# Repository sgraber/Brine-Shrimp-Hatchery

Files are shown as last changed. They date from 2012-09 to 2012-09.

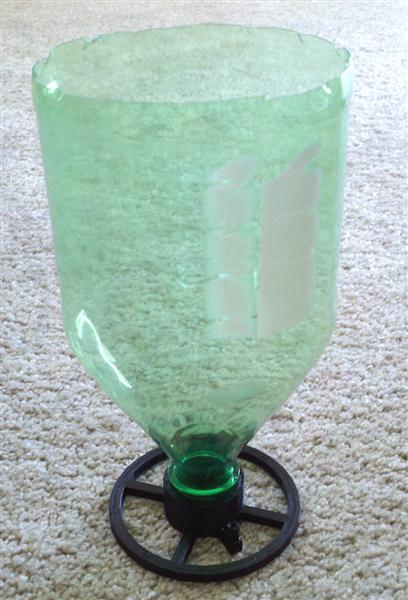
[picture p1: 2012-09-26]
hatchery-assembled.jpg

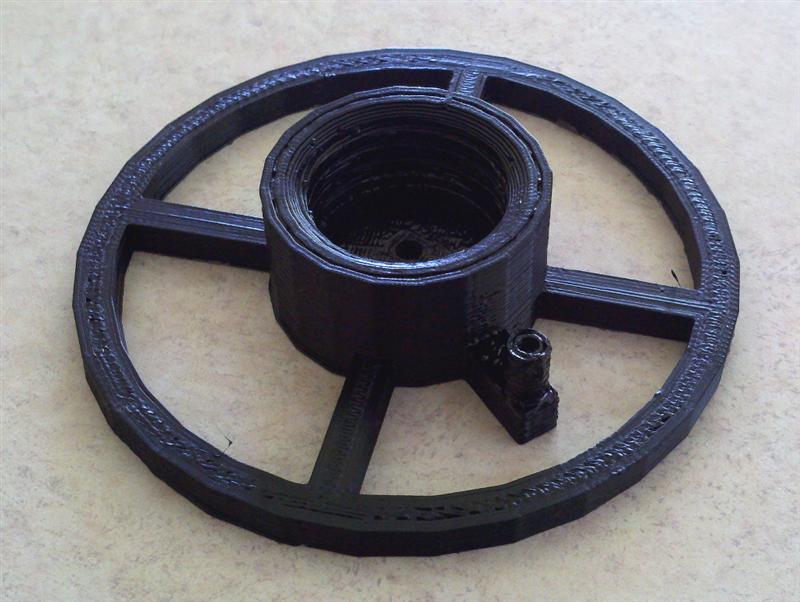
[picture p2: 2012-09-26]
base.jpg

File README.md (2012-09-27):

# Brine Shrimp Hatchery

Released under Creative Commons Attribution-NonCommercial-ShareAlike 3.0 Unported: http://creativecommons.org/licenses/by-nc-sa/3.0/legalcode

This is a simple brine shrimp hatchery base for culturing brine shrimp for fish breeders.

Print it out and screw on a plastic 2 liter bottle with it's base cut off (see photo at left). 

Once printed, I suggest brushing the inside with acetone to make it water tight. Optionally, add a rubber o-ring at the bottom of the threads to help seal it even more. Attach the airline from your air pump to the nipple protruding vertically from the hatchery base.

Make sure to use an airline check valve in case of a power outage as one does not want the water in this hatchery to back flow into the air pump.

Requires "2LscrewPositive.11.stl" from "2 Liter bottle threads" found at: thingiverse.com/thing:10489 (included in this repository)

Place this file in the same directory as the scad file from this thing if you wish to modify it.

I'd recommend printing this at a high percent infill and with 2 shells in order to waterproof it further. Coating the inside with acetone or an ABS/acetone mix helps too.

The o-ring that I ended up using was a simple red-brown o-ring used for sealing the connections for garden hoses. I bought a 10-pack for $1.37 at my local hardware store.

For information on how to culture brine shrimp, please see the following articles:

1. The Breeder's Net: Artemia Nauplii As A Food Source
By Frank Marini, Ph.D.
http://www.advancedaquarist.com/2002/12/breeder

2. Breeder's Net : Amazing Artemia!
By Suzy Applegarth
http://www.advancedaquarist.com/2008/3/breeder

If you are interested in breeding marine fish, I highly suggest checking out the Marine Breeding Initiative at mbisite.org/

Enjoy!

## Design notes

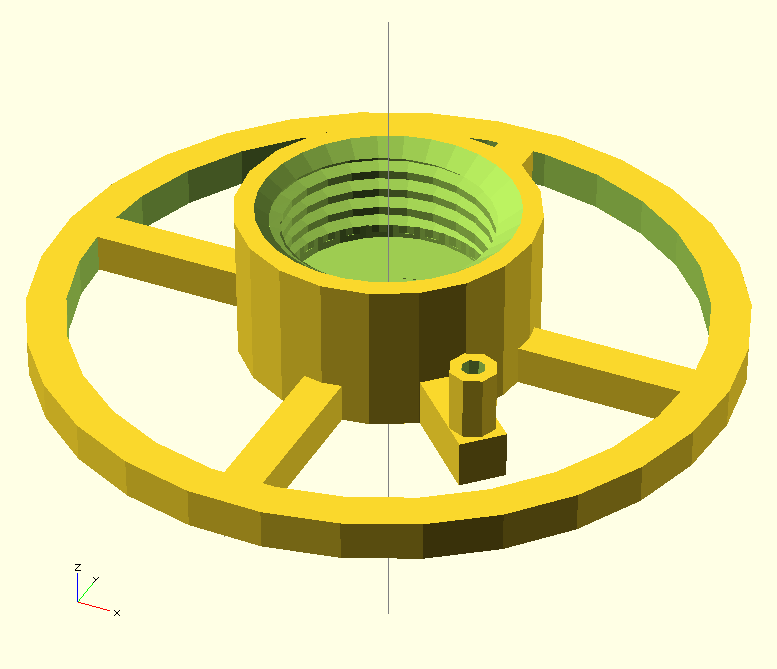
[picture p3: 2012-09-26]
hatchery.png

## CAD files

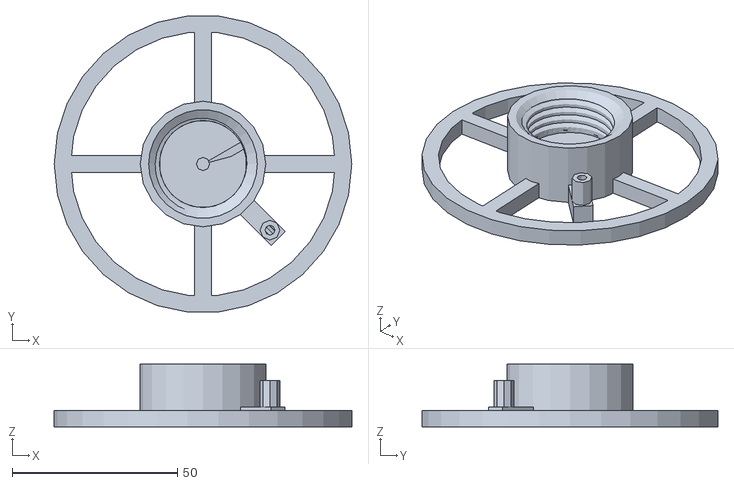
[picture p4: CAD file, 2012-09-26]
hatchery.stl
90.0 x 89.5 x 19.0

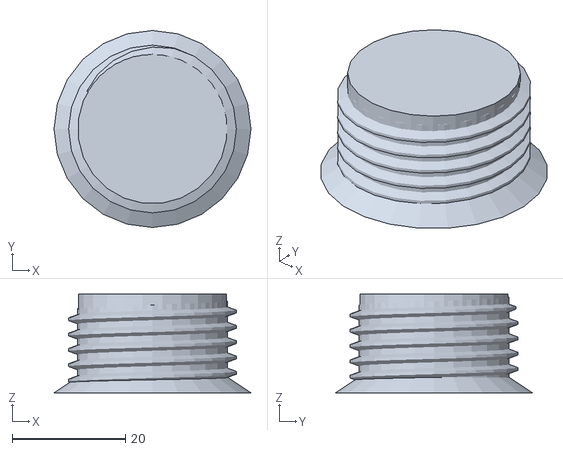
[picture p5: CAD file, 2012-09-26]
2LscrewPositive.11.stl
34.8 x 34.8 x 17.4

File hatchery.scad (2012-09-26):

// THING: BRINE SHRIMP HATCHERY BASE
// AUTHOR: SHANE GRABER
// ----------------------------
// This is a simple brine shrimp hatchery base that one screws onto a plastic
// 2 liter bottle with it's base cut off. Once printed, I suggest brushing the 
// inside with acetone to make it water tight. Optionally, add a rubber o-ring
// at the bottom of the threads to help seal it even more. Attach the airline 
// from your air pump to the nipple protruding vertically from the hatchery base.
// Make sure to use an airline check valve in case of a power outage as one
// does not want the water in this hatchery to back flow into the air pump.
//
// For information on how to culture brine shrimp, please see the following 
// articles:
//
// 1. The Breeder's Net: Artemia Nauplii As A Food Source
//    By Frank Marini, Ph.D.
//    http://www.advancedaquarist.com/2002/12/breeder
//
// 2. Breeder's Net : Amazing Artemia!
//    By Suzy Applegarth
//    http://www.advancedaquarist.com/2008/3/breeder
//
// Requires "2LscrewPositive.11.stl" from "2 Liter bottle threads" found at:
// http://www.thingiverse.com/thing:10489
//
// Enjoy!
//

difference() {
	union() {

		//outside ring, 5 mm wide, 5 mm high
		difference() {
			cylinder(r=45, h=5, $fn=30);
			cylinder(r=40, h=5.1, $fn=30);
		}

		// bottlecap is 26mm diameter, 19mm tall; shortened relative to thread stl
		difference() {
			cylinder(r=19, h=23-4, $fn=20); // cap
			translate([0,0,22]) rotate([0,180,0]) import("2LscrewPositive.11.stl"); // threads
			translate([0,0,14]) cylinder(r1=10, r2=19, h=7); // bevel due to shortening
		}

		// radial supports, 5 mm wide, 5 mm high
		translate([0,0,2.5]) cube(size=[88,5,5], center=true);
		translate([0,0,2.5]) rotate(90) cube(size=[88,5,5], center=true);

		// airline nipple, 6 mm, sticking out of a 6mm block vertically
		translate([10,-14,0]) rotate([0,0,-45]) cube(size=[15,6,6]);
		translate([20.25,-20,2]) cylinder(r=3, h=12, $fn=8);
		
	}

	// air path, 3 mm hole
	translate([0,0,1]) cylinder(r=2, h=15, $fn=8); // 4 mm hole in cap
	translate([0,0,3]) rotate([45,90,0]) cylinder(r=1.5, h=30, $fn=8); // 3 mm hole in block
	translate([20.25,-20,2]) cylinder(r=1.5, h=15, $fn=8); // 3mm hole in nipple

}
